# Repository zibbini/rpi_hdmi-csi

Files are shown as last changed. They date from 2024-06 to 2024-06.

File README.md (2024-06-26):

# HDMI-CSI converter board for Raspberry Pi

A simple hdmi to csi converter board for 15 pin camera connectors used in Raspberry Pi hardware. 

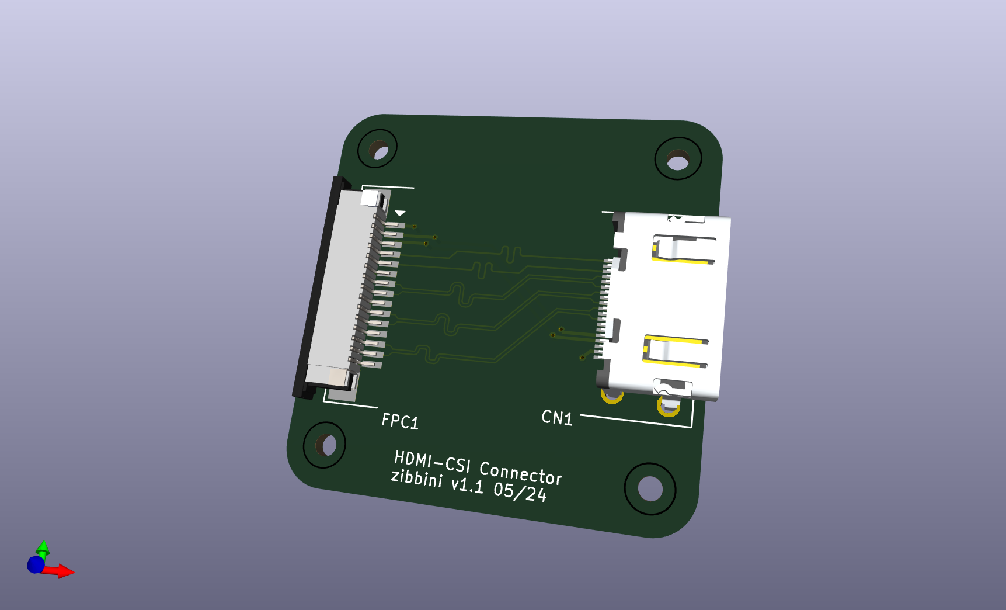
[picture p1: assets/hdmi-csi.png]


Note that the track widths and layer thickness for controlled impedance was calculated with the following stack-up from JLCPCB: [JLC04161H-3313](https://jlcpcb.com/impedance), so you will need to specify this when ordering via JLC. 

Complete gerbers, drill files, BOM and CPL are also included in `/manufacturing` if you just want to order this board without checking out the design.

## Support 

For questions, issues or suggestions please open an issue in the Github repository.

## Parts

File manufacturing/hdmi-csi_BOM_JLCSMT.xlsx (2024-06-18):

Comment | Designator | Footprint | JLCPCB Part #（optional）
10029449-111RLF | CN1 | HDMI-SMD_10029449-001RLF | C427307
X10B25U15T | FPC1 | FPC-SMD_X10B25U15T | C500193

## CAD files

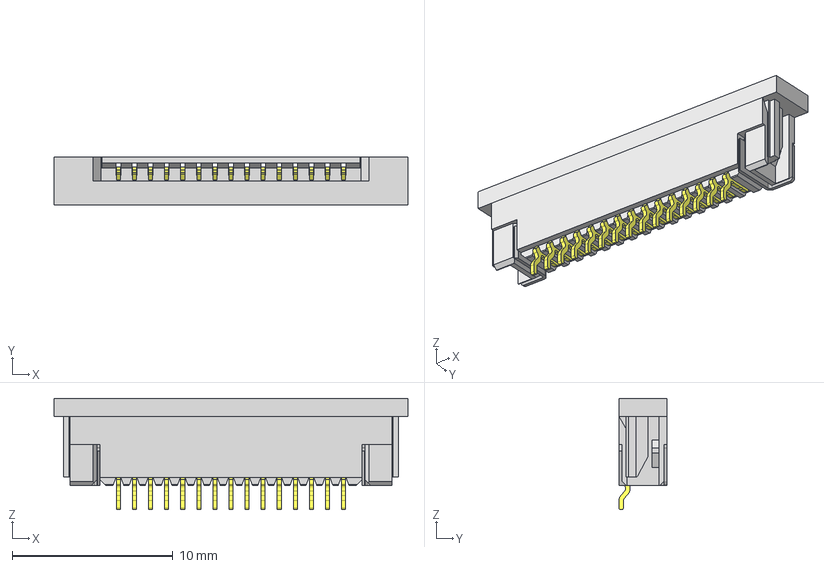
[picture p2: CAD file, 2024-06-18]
kicad/ZF1_15_02_T_WT_TR/ZF1-15-02-T-WT-TR.stp
22.0 x 3.01 x 6.91 mm
ZF1-15-02-WT_housing
ZF1-15-02-WT_wt
ZF1-15-02-WT_contact
ZF1-02_CS2
ZF1-02_cs

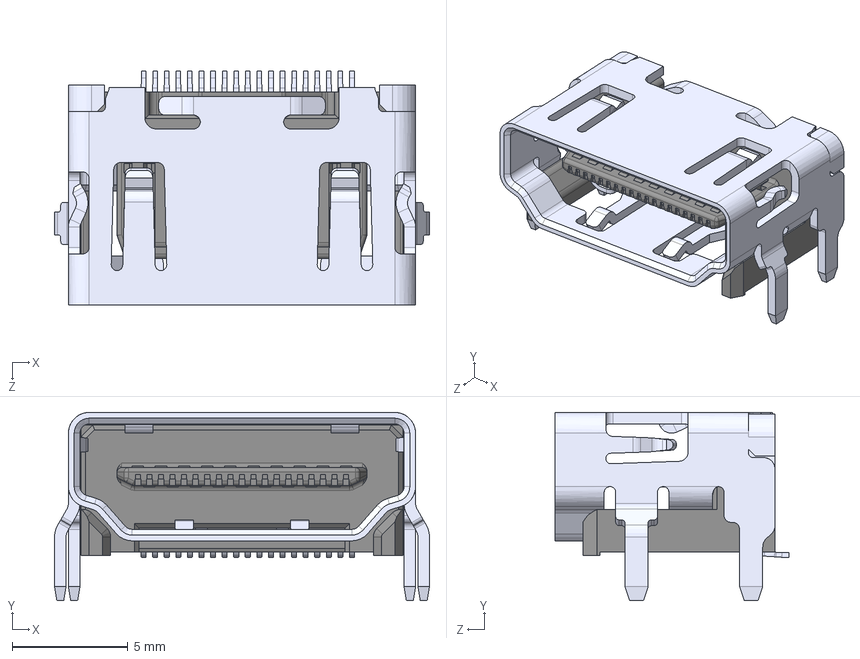
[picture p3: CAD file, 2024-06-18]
kicad/10029449_111RLF/10029449-111RLF.step
16.2 x 8.13 x 10.1 mm

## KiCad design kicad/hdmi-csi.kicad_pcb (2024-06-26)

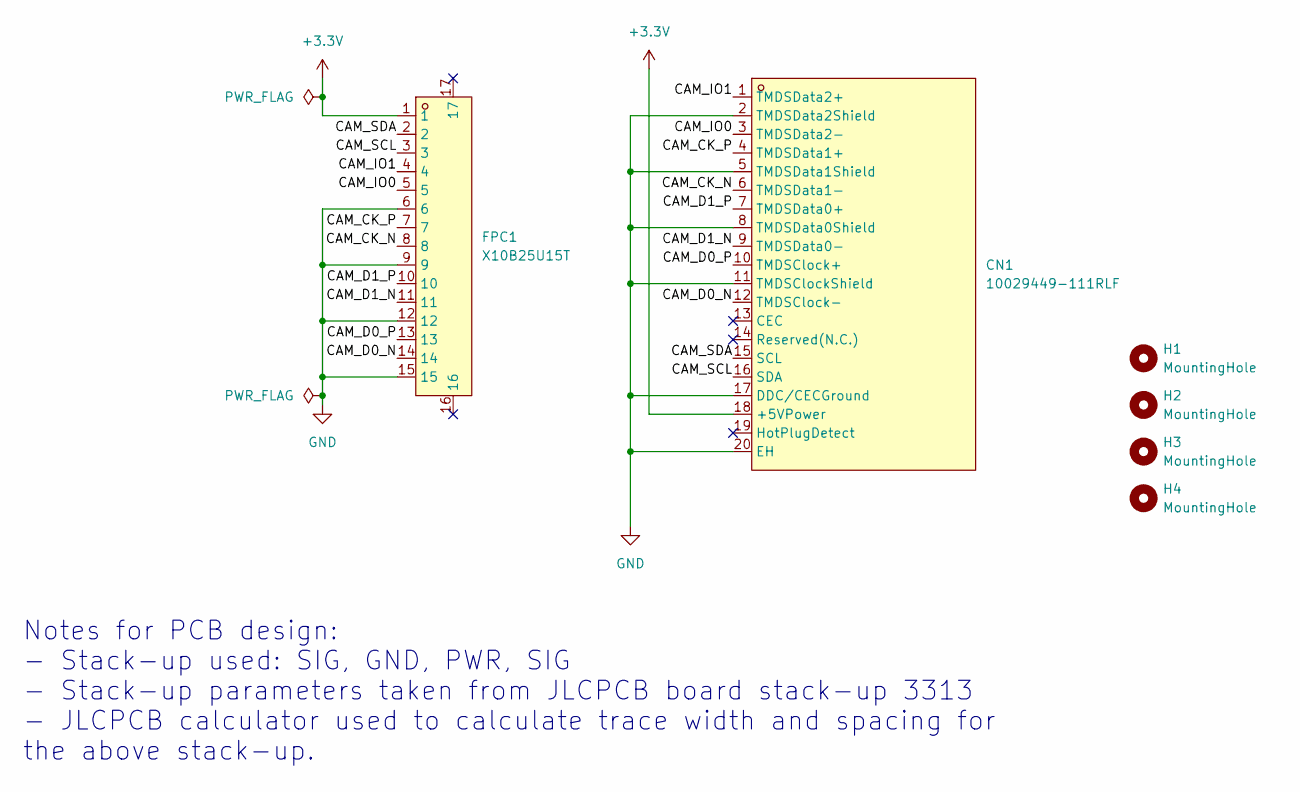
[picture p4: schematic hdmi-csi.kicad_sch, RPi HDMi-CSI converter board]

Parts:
CN1: 10029449-111RLF; HDMI-SMD_10029449-001RLF; LCSC Part C427307
FPC1: X10B25U15T; FPC-SMD_X10B25U15T; LCSC Part C500193
H1, H2, H3, H4: MountingHole; MountingHole_2.1mm

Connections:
+3.3V: CN1.18 (+5VPower), FPC1.1
/CAM_CK_N: CN1.6 (TMDSData1-), FPC1.8
/CAM_CK_P: CN1.4 (TMDSData1+), FPC1.7
/CAM_D0_N: CN1.12 (TMDSClock-), FPC1.14
/CAM_D0_P: CN1.10 (TMDSClock+), FPC1.13
/CAM_D1_N: CN1.9 (TMDSData0-), FPC1.11
/CAM_D1_P: CN1.7 (TMDSData0+), FPC1.10
/CAM_IO0: CN1.3 (TMDSData2-), FPC1.5
/CAM_IO1: CN1.1 (TMDSData2+), FPC1.4
/CAM_SCL: CN1.16 (SDA), FPC1.3
/CAM_SDA: CN1.15 (SCL), FPC1.2
GND: CN1.2 (TMDSData2Shield), CN1.5 (TMDSData1Shield), CN1.8 (TMDSData0Shield), CN1.11 (TMDSClockShield), CN1.17 (DDC/CECGround), CN1.20 (EH), FPC1.6, FPC1.9, FPC1.12, FPC1.15

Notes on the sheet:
Notes for PCB design: - Stack-up used: SIG, GND, PWR, SIG - Stack-up parameters taken from JLCPCB board stack-up 3313 - JLCPCB calculator used to calculate trace width and spacing for the above stack-up.

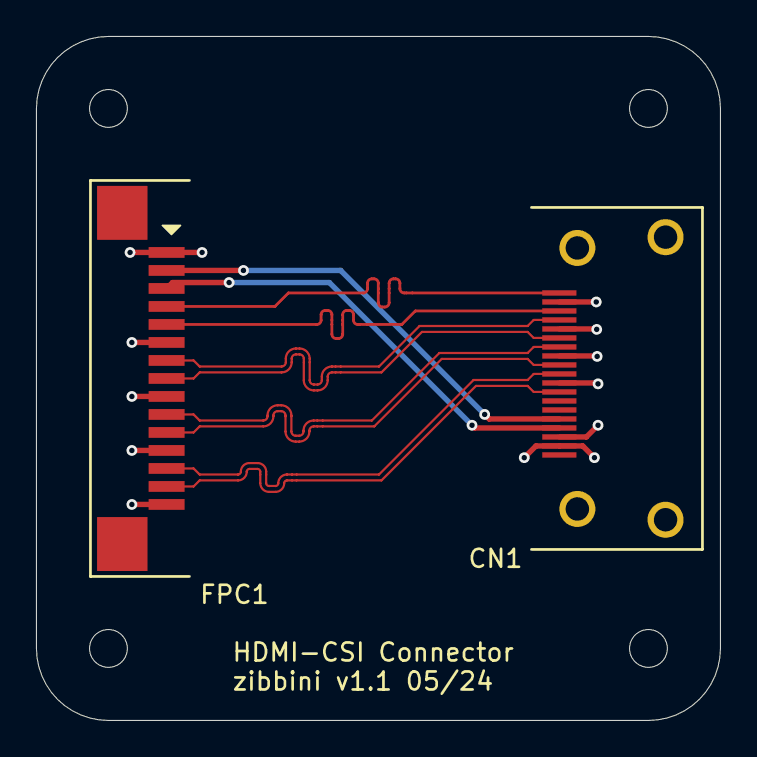
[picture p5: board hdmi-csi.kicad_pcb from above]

Board: 4 copper layers, 38.0 x 38.0 mm, 6 parts (0 on the bottom side), 12 nets.

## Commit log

2024-06-18 Initial commit.
    [10029449-111RLF.step, ZF1-15-02-T-WT-TR.stp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]
2024-06-26 Replace files.
    [hdmi-csi.kicad_pcb, hdmi-csi.kicad_sch]
2024-06-26 Add additional details.
    [hdmi-csi.kicad_pcb, hdmi-csi.kicad_sch]

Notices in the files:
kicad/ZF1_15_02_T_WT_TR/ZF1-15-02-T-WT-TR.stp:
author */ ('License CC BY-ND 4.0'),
